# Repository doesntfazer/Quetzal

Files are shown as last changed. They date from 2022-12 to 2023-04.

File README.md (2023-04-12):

# Quetzal

100% ergo keyboard based on rp2040 Zero Board

Keyboard is tested and working.

Firmware for this board will be in the [Keyboard Dweebs Firmware Repository](https://github.com/doesntfazer/Keyboard-Dweebs-Firmware-repository)

This Board will be using [PRK Firmware](https://github.com/picoruby/prk_firmware) because of the support for Japanese duplex Matrices.

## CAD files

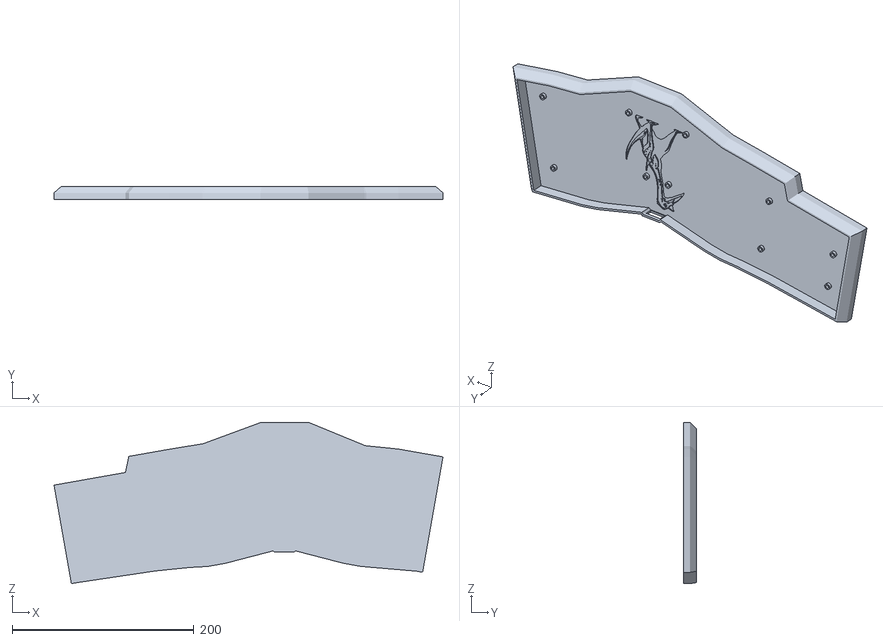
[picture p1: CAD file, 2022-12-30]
Case STL's and F3D/Quetzal - lowpro.stl
427.9 x 14.5 x 177.4

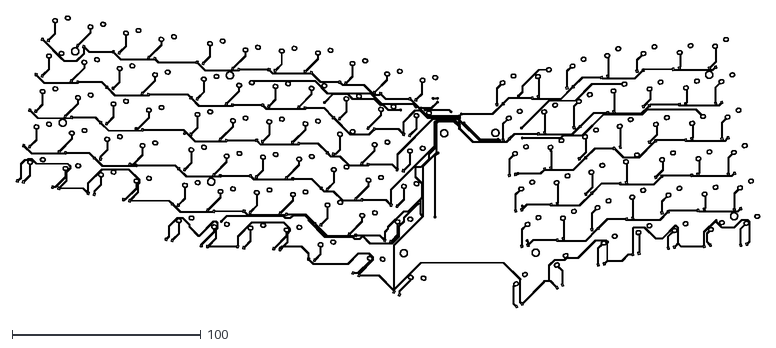
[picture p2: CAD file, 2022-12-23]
DXF/atreuskeypad-B_Cu.dxf
393.9 x 154.7

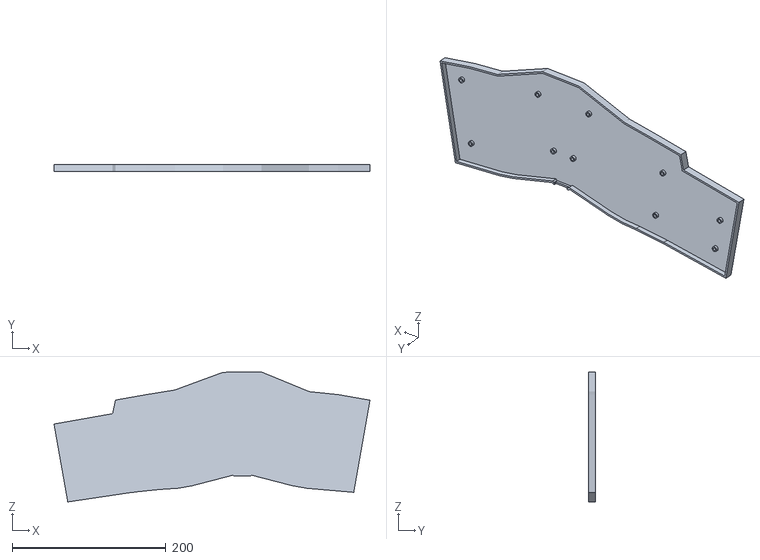
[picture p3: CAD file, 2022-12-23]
Case STL's and F3D/quetzal - minimal.stl
411.7 x 9.00 x 169.2

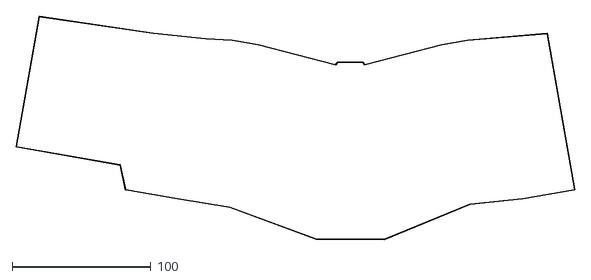
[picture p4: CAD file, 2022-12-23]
DXF/atreuskeypad-Edge_Cuts.dxf
402.6 x 160.8

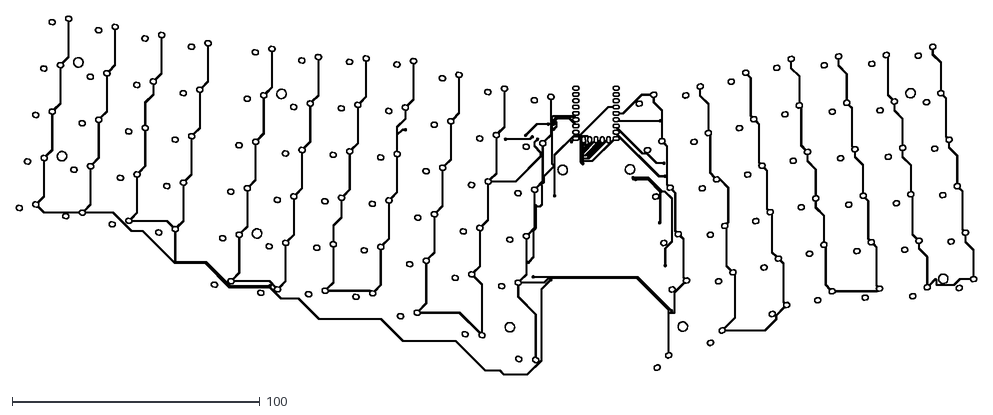
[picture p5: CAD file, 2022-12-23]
DXF/atreuskeypad-F_Cu.dxf
387.8 x 144.9

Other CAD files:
Case STL's and F3D/quetzal - minimal.f3d
DXF/atreuskeypad-B_Mask.dxf
DXF/atreuskeypad-B_Paste.dxf
DXF/atreuskeypad-F_Mask.dxf
DXF/atreuskeypad-F_Paste.dxf
components and pretty/KiCad-RP-Pico-main/SketchUp Model/Pico.skp

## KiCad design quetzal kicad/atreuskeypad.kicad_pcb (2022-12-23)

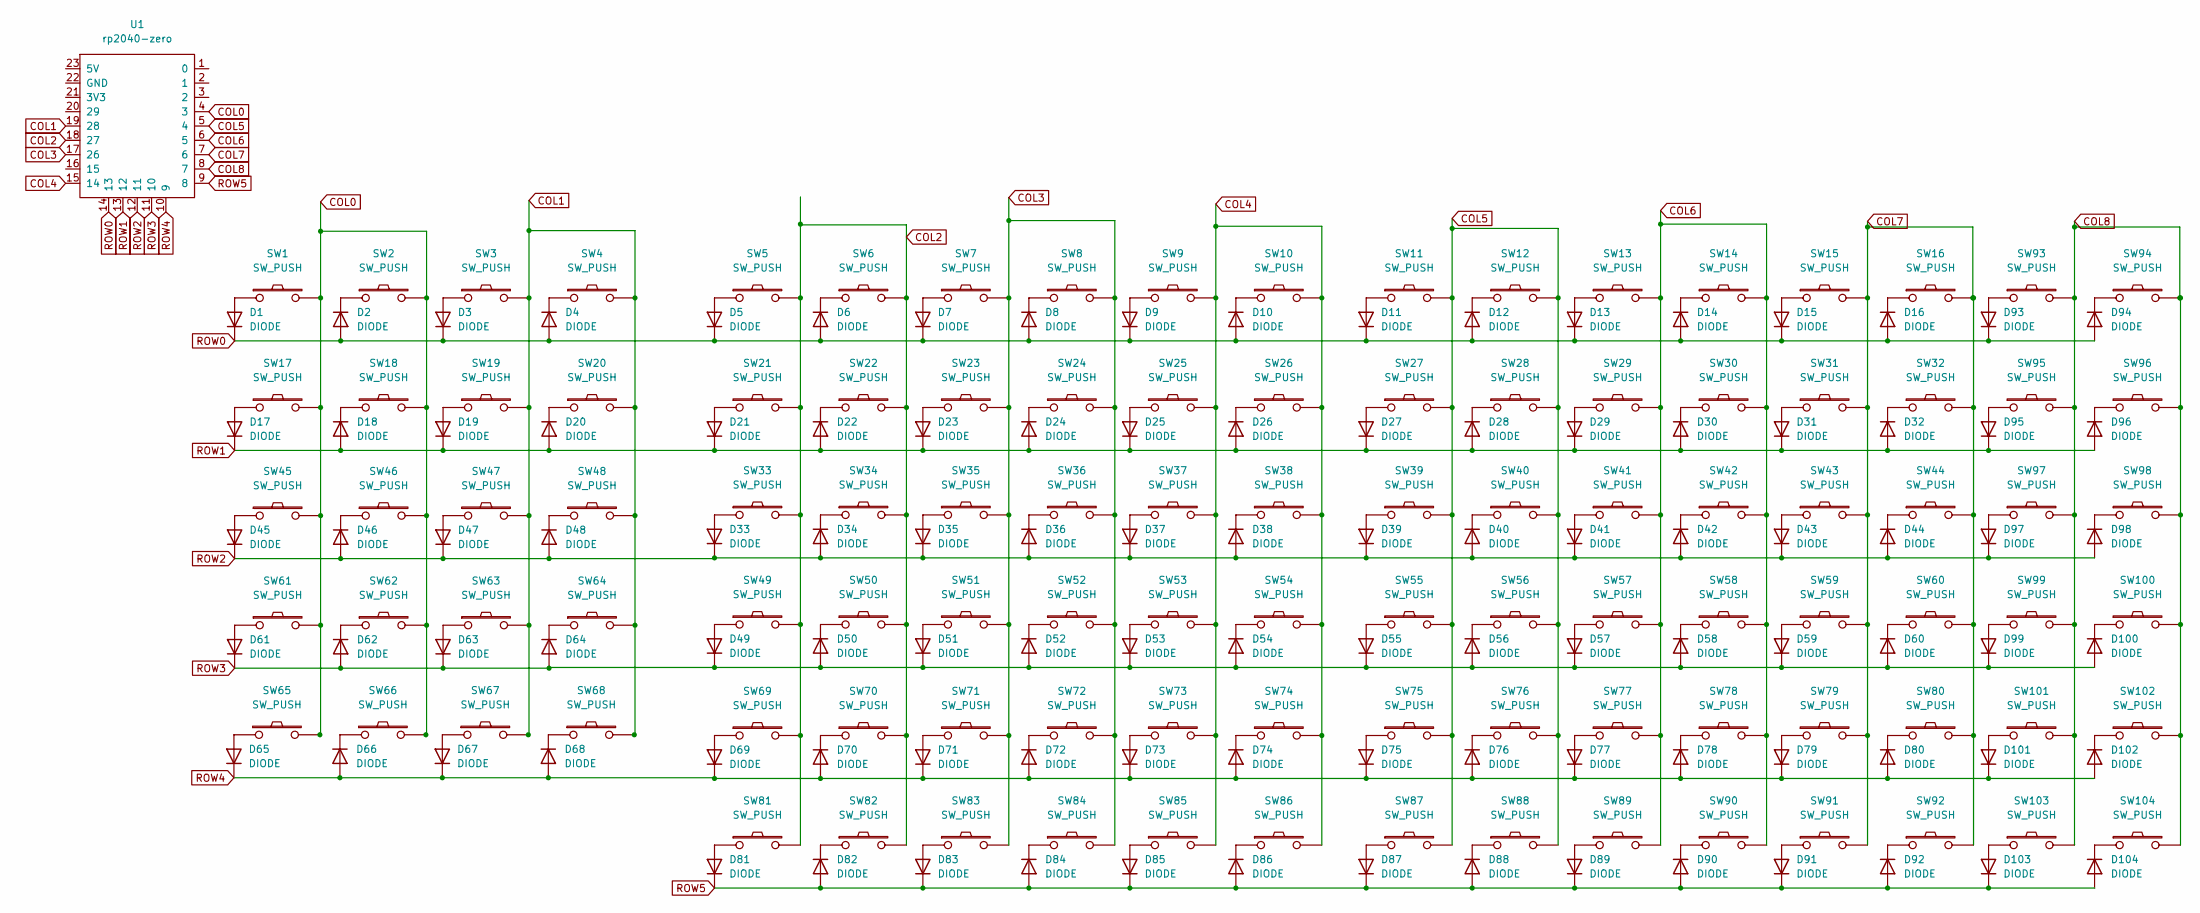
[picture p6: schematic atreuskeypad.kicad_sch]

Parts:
D1, D2, D3, D4, D5, D6, D7, D8, D9, D10, D11, D12, D13, D14, D15, D16, D17, D18, D19, D20, D21, D22, D23, D24, D25, D26, D27, D28, D29, D30, D31, D32, D33, D34, D35, D36, D37, D38, D39, D40, D41, D42, D43, D44, D45, D46, D47, D48, D49, D50, D51, D52, D53, D54, D55, D56, D57, D58, D59, D60, D61, D62, D63, D64, D65, D66, D67, D68, D69, D70, D71, D72, D73, D74, D75, D76, D77, D78, D79, D80, D81, D82, D83, D84, D85, D86, D87, D88, D89, D90, D91, D92, D93, D94, D95, D96, D97, D98, D99, D100, D101, D102, D103, D104: DIODE; D_SOD-123
SW1, SW2, SW3, SW4, SW5, SW6, SW7, SW8, SW9, SW10, SW11, SW12, SW13, SW14, SW15, SW16, SW17, SW18, SW19, SW20, SW21, SW22, SW23, SW24, SW25, SW26, SW27, SW28, SW29, SW30, SW31, SW32, SW33, SW34, SW35, SW36, SW37, SW38, SW39, SW40, SW41, SW42, SW43, SW44, SW45, SW46, SW47, SW48, SW49, SW50, SW51, SW52, SW53, SW54, SW55, SW56, SW57, SW58, SW59, SW60, SW61, SW62, SW63, SW64, SW65, SW66, SW67, SW68, SW69, SW70, SW71, SW72, SW73, SW74, SW75, SW76, SW77, SW78, SW79, SW80, SW81, SW82, SW83, SW84, SW85, SW86, SW87, SW88, SW89, SW90, SW91, SW92, SW93, SW94, SW95, SW96, SW97, SW98, SW99, SW100, SW101, SW102, SW103, SW104: SW_PUSH
U1: rp2040-zero; rp2040-zero-smd-no-cut

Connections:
COL0: SW1.2, SW2.2, SW17.2, SW18.2, SW45.2, SW46.2, SW61.2, SW62.2, SW65.2, SW66.2, U1.4 (3)
COL1: SW3.2, SW4.2, SW19.2, SW20.2, SW47.2, SW48.2, SW63.2, SW64.2, SW67.2, SW68.2, U1.19 (28)
COL2: SW5.2, SW6.2, SW21.2, SW22.2, SW33.2, SW34.2, SW49.2, SW50.2, SW69.2, SW70.2, SW81.2, SW82.2, U1.18 (27)
COL3: SW7.2, SW8.2, SW23.2, SW24.2, SW35.2, SW36.2, SW51.2, SW52.2, SW71.2, SW72.2, SW83.2, SW84.2, U1.17 (26)
COL4: SW9.2, SW10.2, SW25.2, SW26.2, SW37.2, SW38.2, SW53.2, SW54.2, SW73.2, SW74.2, SW85.2, SW86.2, U1.15 (14)
COL5: SW11.2, SW12.2, SW27.2, SW28.2, SW39.2, SW40.2, SW55.2, SW56.2, SW75.2, SW76.2, SW87.2, SW88.2, U1.5 (4)
COL6: SW13.2, SW14.2, SW29.2, SW30.2, SW41.2, SW42.2, SW57.2, SW58.2, SW77.2, SW78.2, SW89.2, SW90.2, U1.6 (5)
COL7: SW15.2, SW16.2, SW31.2, SW32.2, SW43.2, SW44.2, SW59.2, SW60.2, SW79.2, SW80.2, SW91.2, SW92.2, U1.7 (6)
COL8: SW93.2, SW94.2, SW95.2, SW96.2, SW97.2, SW98.2, SW99.2, SW100.2, SW101.2, SW102.2, SW103.2, SW104.2, U1.8 (7)
unnamed: D1.1 (A), SW1.1
unnamed: D2.2 (K), SW2.1
unnamed: D3.1 (A), SW3.1
unnamed: D4.2 (K), SW4.1
unnamed: D5.1 (A), SW5.1
unnamed: D6.2 (K), SW6.1
unnamed: D7.1 (A), SW7.1
unnamed: D8.2 (K), SW8.1
unnamed: D9.1 (A), SW9.1
unnamed: D10.2 (K), SW10.1
unnamed: D11.1 (A), SW11.1
unnamed: D12.2 (K), SW12.1
unnamed: D13.1 (A), SW13.1
unnamed: D14.2 (K), SW14.1
unnamed: D15.1 (A), SW15.1
unnamed: D16.2 (K), SW16.1
unnamed: D17.1 (A), SW17.1
unnamed: D18.2 (K), SW18.1
unnamed: D19.1 (A), SW19.1
unnamed: D20.2 (K), SW20.1
unnamed: D21.1 (A), SW21.1
unnamed: D22.2 (K), SW22.1
unnamed: D23.1 (A), SW23.1
unnamed: D24.2 (K), SW24.1
unnamed: D25.1 (A), SW25.1
unnamed: D26.2 (K), SW26.1
unnamed: D27.1 (A), SW27.1
unnamed: D28.2 (K), SW28.1
unnamed: D29.1 (A), SW29.1
unnamed: D30.2 (K), SW30.1
unnamed: D31.1 (A), SW31.1
unnamed: D32.2 (K), SW32.1
unnamed: D33.1 (A), SW33.1
unnamed: D34.2 (K), SW34.1
unnamed: D35.1 (A), SW35.1
unnamed: D36.2 (K), SW36.1
unnamed: D37.1 (A), SW37.1
unnamed: D38.2 (K), SW38.1
unnamed: D39.1 (A), SW39.1
unnamed: D40.2 (K), SW40.1
unnamed: D41.1 (A), SW41.1
unnamed: D42.2 (K), SW42.1
unnamed: D43.1 (A), SW43.1
unnamed: D44.2 (K), SW44.1
unnamed: D45.1 (A), SW45.1
unnamed: D46.2 (K), SW46.1
unnamed: D47.1 (A), SW47.1
unnamed: D48.2 (K), SW48.1
unnamed: D49.1 (A), SW49.1
unnamed: D50.2 (K), SW50.1
unnamed: D51.1 (A), SW51.1
unnamed: D52.2 (K), SW52.1
unnamed: D53.1 (A), SW53.1
unnamed: D54.2 (K), SW54.1
unnamed: D55.1 (A), SW55.1
unnamed: D56.2 (K), SW56.1
unnamed: D57.1 (A), SW57.1
unnamed: D58.2 (K), SW58.1
unnamed: D59.1 (A), SW59.1
unnamed: D60.2 (K), SW60.1
unnamed: D61.1 (A), SW61.1
unnamed: D62.2 (K), SW62.1
unnamed: D63.1 (A), SW63.1
unnamed: D64.2 (K), SW64.1
unnamed: D65.1 (A), SW65.1
unnamed: D66.2 (K), SW66.1
unnamed: D67.1 (A), SW67.1
unnamed: D68.2 (K), SW68.1
unnamed: D69.1 (A), SW69.1
unnamed: D70.2 (K), SW70.1
unnamed: D71.1 (A), SW71.1
unnamed: D72.2 (K), SW72.1
unnamed: D73.1 (A), SW73.1
unnamed: D74.2 (K), SW74.1
unnamed: D75.1 (A), SW75.1
unnamed: D76.2 (K), SW76.1
unnamed: D77.1 (A), SW77.1
unnamed: D78.2 (K), SW78.1
unnamed: D79.1 (A), SW79.1
unnamed: D80.2 (K), SW80.1
unnamed: D81.1 (A), SW81.1
unnamed: D82.2 (K), SW82.1
unnamed: D83.1 (A), SW83.1
unnamed: D84.2 (K), SW84.1
unnamed: D85.1 (A), SW85.1
unnamed: D86.2 (K), SW86.1
unnamed: D87.1 (A), SW87.1
unnamed: D88.2 (K), SW88.1
unnamed: D89.1 (A), SW89.1
unnamed: D90.2 (K), SW90.1
unnamed: D91.1 (A), SW91.1
unnamed: D92.2 (K), SW92.1
unnamed: D93.1 (A), SW93.1
unnamed: D94.2 (K), SW94.1
unnamed: D95.1 (A), SW95.1
unnamed: D96.2 (K), SW96.1
unnamed: D97.1 (A), SW97.1
unnamed: D98.2 (K), SW98.1
unnamed: D99.1 (A), SW99.1
unnamed: D100.2 (K), SW100.1
unnamed: D101.1 (A), SW101.1
unnamed: D102.2 (K), SW102.1
unnamed: D103.1 (A), SW103.1
unnamed: D104.2 (K), SW104.1
ROW0: D1.2 (K), D2.1 (A), D3.2 (K), D4.1 (A), D5.2 (K), D6.1 (A), D7.2 (K), D8.1 (A), D9.2 (K), D10.1 (A), D11.2 (K), D12.1 (A), D13.2 (K), D14.1 (A), D15.2 (K), D16.1 (A), D93.2 (K), D94.1 (A), U1.14 (13)
ROW1: D17.2 (K), D18.1 (A), D19.2 (K), D20.1 (A), D21.2 (K), D22.1 (A), D23.2 (K), D24.1 (A), D25.2 (K), D26.1 (A), D27.2 (K), D28.1 (A), D29.2 (K), D30.1 (A), D31.2 (K), D32.1 (A), D95.2 (K), D96.1 (A), U1.13 (12)
ROW2: D33.2 (K), D34.1 (A), D35.2 (K), D36.1 (A), D37.2 (K), D38.1 (A), D39.2 (K), D40.1 (A), D41.2 (K), D42.1 (A), D43.2 (K), D44.1 (A), D45.2 (K), D46.1 (A), D47.2 (K), D48.1 (A), D97.2 (K), D98.1 (A), U1.12 (11)
ROW3: D49.2 (K), D50.1 (A), D51.2 (K), D52.1 (A), D53.2 (K), D54.1 (A), D55.2 (K), D56.1 (A), D57.2 (K), D58.1 (A), D59.2 (K), D60.1 (A), D61.2 (K), D62.1 (A), D63.2 (K), D64.1 (A), D99.2 (K), D100.1 (A), U1.11 (10)
ROW4: D65.2 (K), D66.1 (A), D67.2 (K), D68.1 (A), D69.2 (K), D70.1 (A), D71.2 (K), D72.1 (A), D73.2 (K), D74.1 (A), D75.2 (K), D76.1 (A), D77.2 (K), D78.1 (A), D79.2 (K), D80.1 (A), D101.2 (K), D102.1 (A), U1.10 (9)
ROW5: D81.2 (K), D82.1 (A), D83.2 (K), D84.1 (A), D85.2 (K), D86.1 (A), D87.2 (K), D88.1 (A), D89.2 (K), D90.1 (A), D91.2 (K), D92.1 (A), D103.2 (K), D104.1 (A), U1.9 (8)

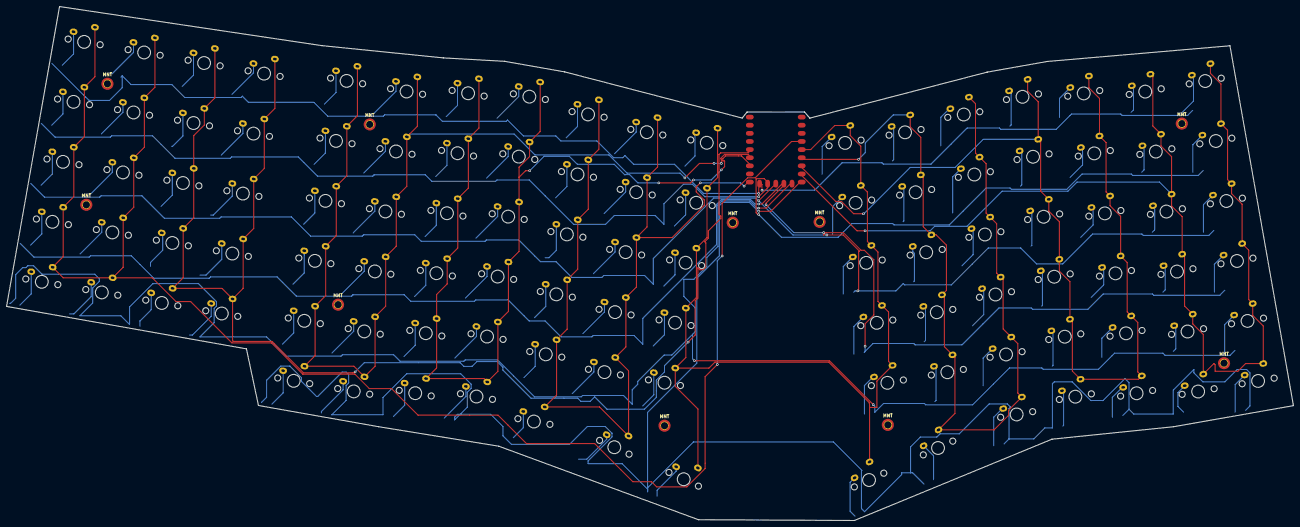
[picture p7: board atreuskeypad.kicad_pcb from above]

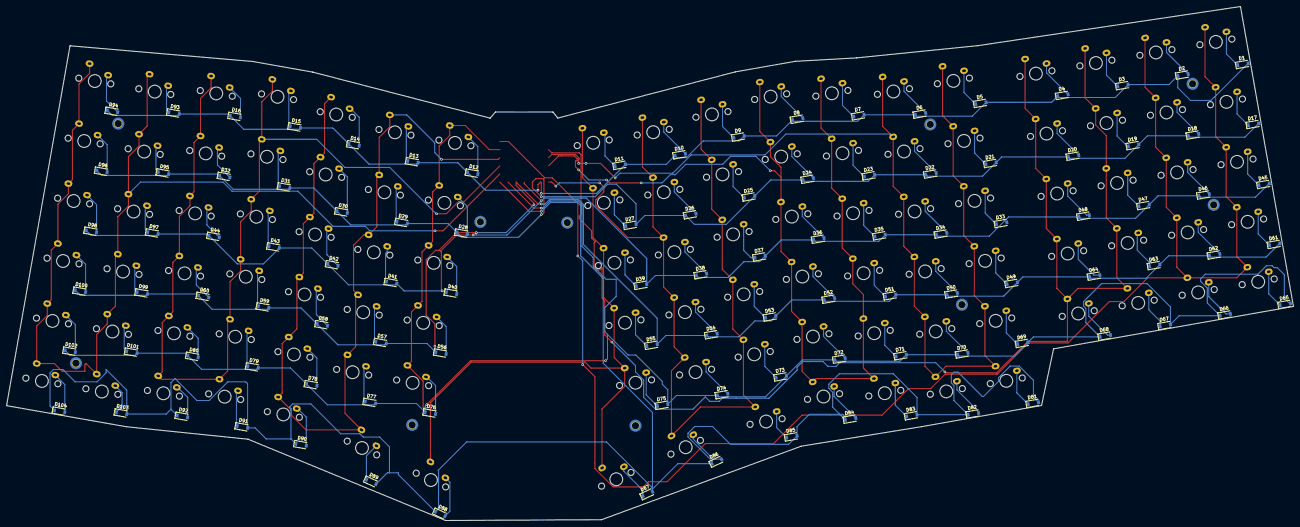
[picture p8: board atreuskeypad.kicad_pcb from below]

Board: 2 copper layers, 402.5 x 160.8 mm, 219 parts (104 on the bottom side), 119 nets.

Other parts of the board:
MNT: MountingHole_2.2mm_M2_DIN965_Pad_TopBottom
MNT#2, MNT#3, MNT#4, MNT#5, MNT#6, MNT#7, MNT#8, MNT#9, MNT#10: MountingHole_2.2mm_M2_DIN965_Pad_TopBottom

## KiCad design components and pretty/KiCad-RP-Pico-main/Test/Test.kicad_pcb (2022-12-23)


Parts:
J1, J2: Conn_01x20; PinSocket_1x20_P1.00mm_Vertical
J3: Conn_01x03; PinSocket_1x03_P1.00mm_Vertical
U1: Pico; RPi_Pico_SMD_TH

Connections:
GND: J1.3, J1.8, J1.13, J1.18, J2.3, J2.13, J2.18, J3.2, U1.3 (GND), U1.8 (GND), U1.13 (GND), U1.18 (GND), U1.23 (GND), U1.28 (GND), U1.38 (GND), U1.42 (GND)
unnamed: J1.1, U1.1 (GPIO0)
unnamed: J1.2, U1.2 (GPIO1)
unnamed: J1.4, U1.4 (GPIO2)
unnamed: J1.5, U1.5 (GPIO3)
unnamed: J1.6, U1.6 (GPIO4)
unnamed: J1.7, U1.7 (GPIO5)
unnamed: J1.9, U1.9 (GPIO6)
unnamed: J1.10, U1.10 (GPIO7)
unnamed: J1.11, U1.11 (GPIO8)
unnamed: J1.12, U1.12 (GPIO9)
unnamed: J1.14, U1.14 (GPIO10)
unnamed: J1.15, U1.15 (GPIO11)
unnamed: J1.16, U1.16 (GPIO12)
unnamed: J1.17, U1.17 (GPIO13)
unnamed: J1.19, U1.19 (GPIO14)
unnamed: J1.20, U1.20 (GPIO15)
unnamed: J2.1, U1.40 (VBUS)
unnamed: J2.2, U1.39 (VSYS)
unnamed: J2.4, U1.37 (3V3_EN)
unnamed: J2.5, U1.36 (3V3)
unnamed: J2.6, U1.35 (ADC_VREF)
unnamed: J2.7, U1.34 (GPIO28_ADC2)
unnamed: J2.8, U1.33 (AGND)
unnamed: J2.9, U1.32 (GPIO27_ADC1)
unnamed: J2.10, U1.31 (GPIO26_ADC0)
unnamed: J2.11, U1.30 (RUN)
unnamed: J2.12, U1.29 (GPIO22)
unnamed: J2.14, U1.27 (GPIO21)
unnamed: J2.15, U1.26 (GPIO20)
unnamed: J2.16, U1.25 (GPIO19)
unnamed: J2.17, U1.24 (GPIO18)
unnamed: J2.19, U1.22 (GPIO17)
unnamed: J2.20, U1.21 (GPIO16)
unnamed: J3.1, U1.43 (SWDIO)
unnamed: J3.3, U1.41 (SWCLK)


Board: 2 copper layers, 43.0 x 65.0 mm, 4 parts (0 on the bottom side), 36 nets.

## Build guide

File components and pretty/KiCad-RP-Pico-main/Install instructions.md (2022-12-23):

# Install instructions

## 1. Copy the files locally

Copy the `RP-Pico Libraries` folder wherever you like on your computer.

## 2. Install the Raspberry Pi Pico board schema symbol

Use the `KiCad | Preferences | Manage Symbol Libraries...` command to manage the symbol library:



then select the global tab and click on the folder button:



navigate to the `RP-Pico Libraries` folder, select the `MCU_RaspberryPi_and_Boards.kicad_sym` file and open it:



et voilà, the first step is completed:



You can now close the symbol libraries manager window.

## 3. Install the Raspberry Pi Pico board footprint

You can use a similar approach to add the footprint to the footprint libraries manager, but I've found some issues that I've solved using the footprint editor, so here are the steps I suggest you to follow:

Open the footprint editor



wait for the footprints to load... then use the `File | Add Library` command:



confirm the `Global` choice:



and select the `MCU_RaspberriPi_and_Boards.pretty` folder (yes, the folder represent a footprint library on KiCad):



Now the library is installed on KiCad with the Raspberry Pi Pico footprint (double click on it to see it on the editor pane):



Don't close the windows as the next step start from here.

## 4. Install the Raspberry Pi Pico board footprint 3D visual

If not already open, open the the footprint editor

symbol library manager

double click on the `RPi_Pico_SMD_TH` footprint from the `MCU_RaspberriPi_and_Boards` library and then click on the `Footprint properties` icon:



In the footprint properties window, first select the `3D Settings` tab. Please note that the preview shows only the PCB board with the footprint added on step 3, without any 3D representation of the Raspberry Pi Pico board. Now click on the folder icon to add the 3D model:



Navigate to the `RP-Pico Libraries` folder, select the `Pico.wrl` file and wait until the model is shown in the right panel, then confirm with OK:



The model is already scaled and translated to match the footprint:



now close the `Footprint Properties` window, and the `Footprint Editor`, obviously saving the changes.

## Conclusion

Now that you've installed the schema and footprint and added the 3D model to the footprint, you can use the Raspberry Pi Pico board on your KiCad projects.

I've also added a test KiCad Project on the `Test` folder, that you can use to see an example of it.

Have fun!

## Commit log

2022-12-23 added case files
    [bigboard v1.f3d, bigboard v1.stl]
2022-12-23 adding mask
    [atreuskeypad-B_Cu.gbr, atreuskeypad-B_Mask.gbr, atreuskeypad-B_Paste.gbr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]
2022-12-23 updated gerber, added silkscreen
    [atreuskeypad-B_Cu.gbr, atreuskeypad-B_Mask.gbr, atreuskeypad-B_Paste.gbr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]
2022-12-29 Fixed my dumb mistake
    The rp2040 Zero is supposed to have a cutout. I removed the cutout because it was causing issues with my kicad Gerber's. I added an appropriate cut back to this so that the MCU can sit flush.
2022-12-29 new gerbers with my fixed mistake
    [atreuskeypad-B_Cu.gbr, atreuskeypad-B_Mask.gbr, atreuskeypad-B_Paste.gbr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]
2022-12-29 Gerber's with the fill
    [atreuskeypad-B_Cu.gbr, atreuskeypad-B_Mask.gbr, atreuskeypad-B_Paste.gbr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]
2022-12-30 cases
    added more cases
    [Quetzal - hi-pro.stl, quetzal - minimal - lowpro.f3d, quetzal - minimal - lowpro.stl]
2022-12-31 renamed to lowpro
    Low profile - this means that the case comes up to the switch plate. (or on this case, where the switch plate would be if it weren't pcb mount.) You can still see the tops of the switches still.
    [Quetzal - lowpro.stl, quetzal - minimal - lowpro.f3d, quetzal - minimal - lowpro.stl]
2022-12-31 renamed to minimal
    Minimal means that it uses as little material as possible. Just enough to cover the pcb, and still to be fairly rigid.
    [quetzal - minimal.f3d, quetzal - minimal.stl]
2023-04-03 fixed backwards diode in schematic
    spice_simulation diode symbols are backwards compared to their PCB footprint. Changed all spice_simulation diode symbols to 1N4148W symbols and verified PCB now matches.
    [atreuskeypad.kicad_sch]
